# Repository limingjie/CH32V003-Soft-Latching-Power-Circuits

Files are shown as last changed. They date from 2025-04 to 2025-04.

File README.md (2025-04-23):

# CH32V003 Soft Latching Power Circuits

The Soft Latching Power Circuit is ideal for battery-powered applications, as it draws no current once the system is powered down.

## Schematic

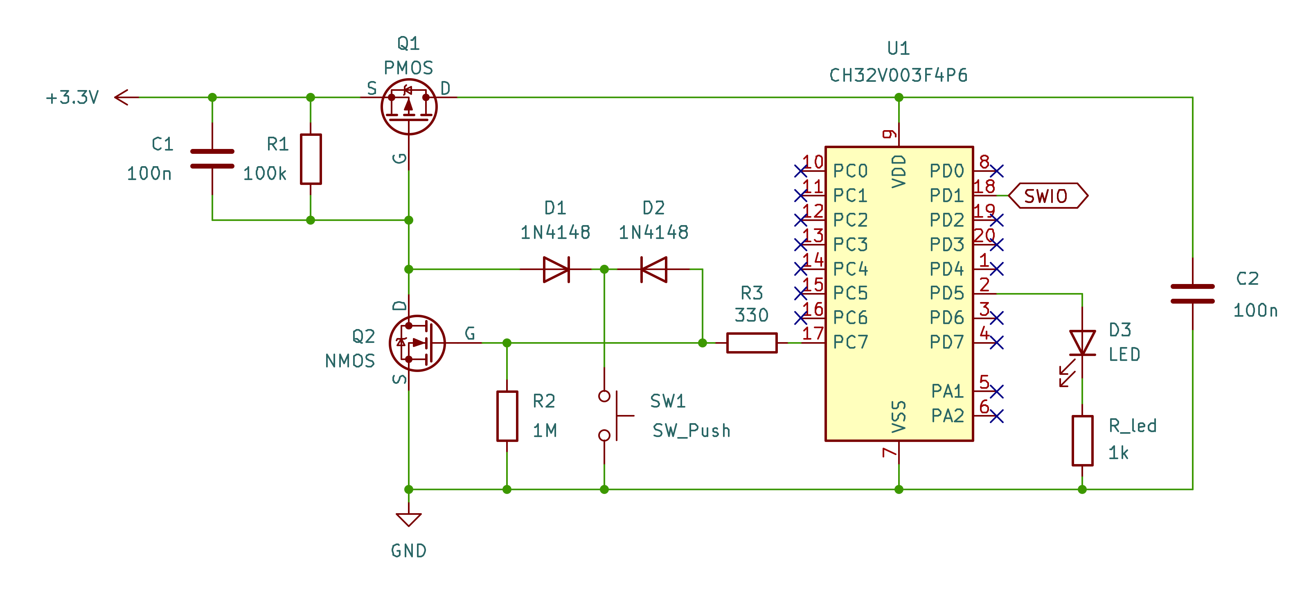
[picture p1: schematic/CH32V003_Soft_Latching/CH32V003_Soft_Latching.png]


- `R1` and `C1` hold `Q1` in the off state, while `R2` keeps `Q2` turned off.
- Pressing the button `SW1` pulls the gate of `Q1` low, allowing power to reach the MCU.
- Once powered, the MCU configures `PC7` as an input with the internal pull-up resistor, which latches both `Q1` and `Q2` on.
- The MCU can also monitor the state of the button through pin `PC7`.
- To shut down the circuit, the MCU configures `PC7` as an input with the internal pull-down resistor, turning off both `Q1` and `Q2`.

## Notes

The circuit works flawlessly with the CH32V003!

Initially, I tested it with the CH552, but it never operated reliably. This is likely due to the CH552’s GPIOs defaulting to quasi-bidirectional mode (typical for 8051 cores), which includes an internal pull-up resistor. As a result, `Q2` may not be fully turned off. In contrast, the CH32V003 GPIOs default to high-impedance input mode, which avoids this issue.

## References

- [Andrew Levido: Soft Latching Power Circuits](https://circuitcellar.com/resources/quickbits/soft-latching-power-circuits/)
- [CNLohr: ch32v003fun](https://github.com/cnlohr/ch32v003fun)
- [A Guide to Debouncing](https://my.eng.utah.edu/~cs5780/debouncing.pdf)
- [The simplest button debounce solution](https://www.e-tinkers.com/2021/05/the-simplest-button-debounce-solution/)
- [Museum of the Game - Let's design some POKEY replacements](https://forums.arcade-museum.com/threads/lets-design-some-pokey-replacements.515774/post-4623716)

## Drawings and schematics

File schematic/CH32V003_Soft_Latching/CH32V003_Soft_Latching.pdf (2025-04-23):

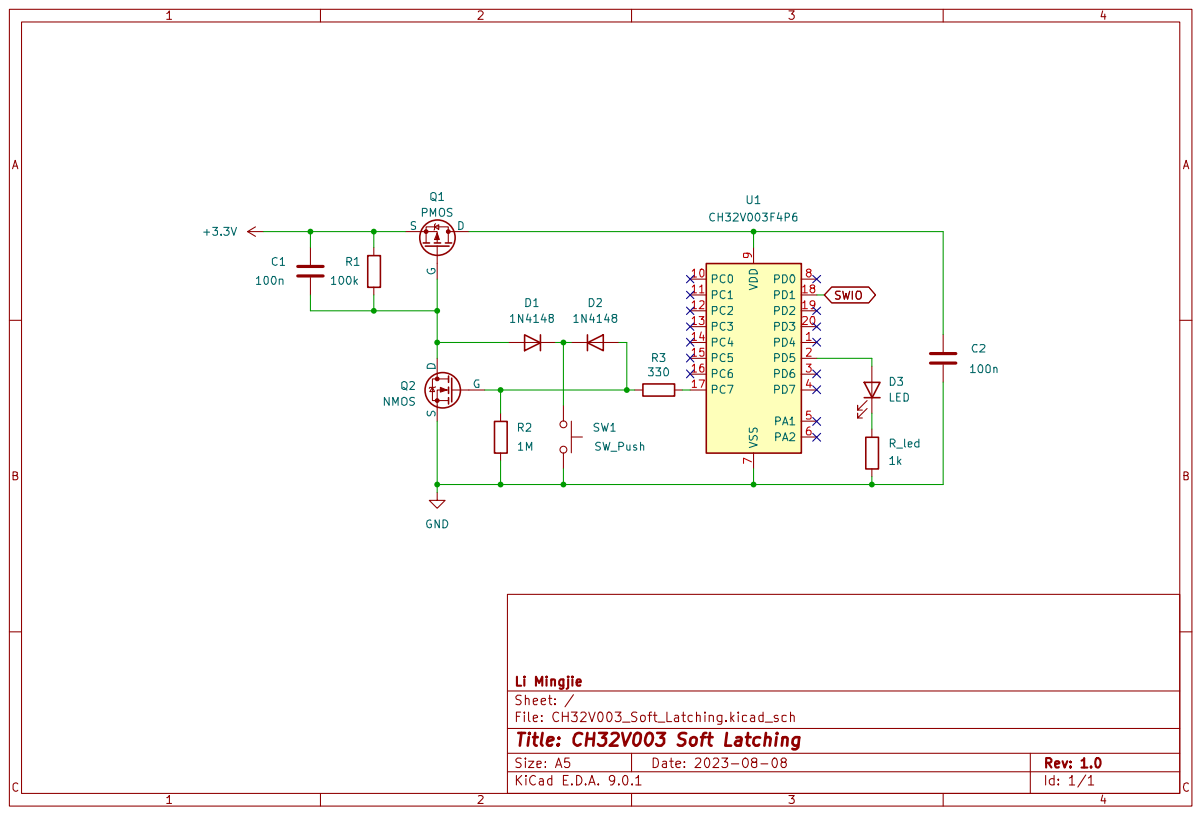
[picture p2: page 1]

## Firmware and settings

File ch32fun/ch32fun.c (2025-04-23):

// Mixture of embedlibc, and ch32v00x_startup.c
// Use with newlib headers.
// Mixture of weblibc, mini-printf and ???
/* This file contains the following functions:

// libc (via musl) mixture and miniprintf

int printf( const char* format, ... )
int vprintf(const char* format, va_list args)
int snprintf( char * buffer, unsigned int buffer_len, const char* format, ... )
int sprintf( char * buffer, const char * format, ... )
size_t wcrtomb(char *restrict s, wchar_t wc, mbstate_t *restrict st)
int wctomb(char *s, wchar_t wc)
size_t strlen(const char *s)
size_t strnlen(const char *s, size_t n)
void *memset(void *dest, int c, size_t n)
char *strcpy(char *d, const char *s)
char *strncpy(char *d, const char *s, size_t n)
int strcmp(const char *l, const char *r)
int strncmp(const char *_l, const char *_r, size_t n)
static char *twobyte_strstr(const unsigned char *h, const unsigned char *n)
static char *threebyte_strstr(const unsigned char *h, const unsigned char *n)
static char *fourbyte_strstr(const unsigned char *h, const unsigned char *n)
static char *twoway_strstr(const unsigned char *h, const unsigned char *n)
char *strstr(const char *h, const char *n)
char *strchr(const char *s, int c)
void *__memrchr(const void *m, int c, size_t n)
char *strrchr(const char *s, int c)
void *memcpy(void *dest, const void *src, size_t n)
int memcmp(const void *vl, const void *vr, size_t n)
void *memmove(void *dest, const void *src, size_t n)
void *memchr(const void *src, int c, size_t n)
int puts(const char *s)
int mini_itoa(long value, unsigned int radix, int uppercase, int unsig,
	 char *buffer)
int mini_vsnprintf(char *buffer, unsigned int buffer_len, const char *fmt, va_list va)
int mini_vpprintf(int (*puts)(char* s, int len, void* buf), void* buf, const char *fmt, va_list va)
int mini_snprintf(char* buffer, unsigned int buffer_len, const char *fmt, ...)
int mini_pprintf(int (*puts)(char*s, int len, void* buf), void* buf, const char *fmt, ...)

// IRQ Handling Code
void DefaultIRQHandler( void )
void NMI_RCC_CSS_IRQHandler( void )

// Startup Code
void InterruptVectorDefault( void )
void handle_reset( void )

// Configuration-specific I/O

#if defined( FUNCONF_USE_UARTPRINTF ) && FUNCONF_USE_UARTPRINTF
void SetupUART( int uartBRR )
int _write(int fd, const char *buf, int size)
int putchar(int c)
#endif

#if defined( FUNCONF_USE_DEBUGPRINTF ) && FUNCONF_USE_DEBUGPRINTF
void handle_debug_input( int numbytes, uint8_t * data ) // You can override this!
void poll_input( void )
int _write(int fd, const char *buf, int size)
int putchar(int c)
void SetupDebugPrintf( void )
void WaitForDebuggerToAttach()
#endif

#if (defined( FUNCONF_USE_DEBUGPRINTF ) && !FUNCONF_USE_DEBUGPRINTF) && \
	(defined( FUNCONF_USE_UARTPRINTF ) && !FUNCONF_USE_UARTPRINTF) && \
	(defined( FUNCONF_NULL_PRINTF ) && FUNCONF_NULL_PRINTF)

int _write(int fd, const char *buf, int size)
int putchar(int c)
#endif

void DelaySysTick( uint32_t n )
void SystemInit( void )

#ifdef CPLUSPLUS
extern void __cxa_pure_virtual()
void __libc_init_array(void)
#endif

*/

// We pre-define these, because if the user is (for some awful reason) using gcc-riscv64-linux-gnu with newlib, it will fail to compile if it janks up the stdio/string functions.
#define _SSP_STRING_H_
#define _SSP_STDIO_H_

#include <stdio.h>
#include <string.h>
#include <stdarg.h>
#include <limits.h>
#include <stdint.h>
#include <ch32fun.h>

#define WEAK __attribute__((weak))

WEAK int errno;

static int __puts_uart( char *s, int len, void *buf )
{
	(void)buf;

	_write( 0, s, len );
	return len;
}

WEAK int printf( const char* format, ... )
{
	va_list args;
	va_start( args, format );
	int ret_status = mini_vpprintf(__puts_uart, 0, format, args);
	va_end( args );
	return ret_status;
}

WEAK int vprintf(const char* format, va_list args)
{
	return mini_vpprintf(__puts_uart, 0, format, args);
}

WEAK int snprintf( char * buffer, unsigned int buffer_len, const char* format, ... )
{
	va_list args;
	va_start( args, format );
	int ret = mini_vsnprintf( buffer, buffer_len, format, args );
	va_end( args );
	return ret;
}

WEAK int sprintf( char * buffer, const char * format, ... )
{
	va_list args;
	va_start( args, format );
	int ret = mini_vsnprintf( buffer, INT_MAX, format, args );
	va_end( args );
	return ret;
}

/* Some stuff from MUSL


----------------------------------------------------------------------
Copyright © 2005-2020 Rich Felker, et al.

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
THE SOFTWARE IS PROVIDED "AS IS", WITHOUT WARRANTY OF ANY KIND,
EXPRESS OR IMPLIED, INCLUDING BUT NOT LIMITED TO THE WARRANTIES OF
MERCHANTABILITY, FITNESS FOR A PARTICULAR PURPOSE AND NONINFRINGEMENT.
IN NO EVENT SHALL THE AUTHORS OR COPYRIGHT HOLDERS BE LIABLE FOR ANY
CLAIM, DAMAGES OR OTHER LIABILITY, WHETHER IN AN ACTION OF CONTRACT,
TORT OR OTHERWISE, ARISING FROM, OUT OF OR IN CONNECTION WITH THE
SOFTWARE OR THE USE OR OTHER DEALINGS IN THE SOFTWARE.
----------------------------------------------------------------------

*/

/*
 * mbstate_t is an opaque object to keep conversion state, during multibyte
 * stream conversions.  The content must not be referenced by user programs.
 */

#define CURRENT_UTF8 0
#define IS_CODEUNIT(c) ((unsigned)(c)-0xdf80 < 0x80)
#define MB_CUR_MAX (CURRENT_UTF8 ? 4 : 1)

typedef void * mbstate_t;

#ifdef UNICODE
WEAK size_t wcrtomb(char *restrict s, wchar_t wc, mbstate_t *restrict st)
{
	if (!s) return 1;
	if ((unsigned)wc < 0x80) {
		*s = wc;
		return 1;
	} else if (MB_CUR_MAX == 1) {
		if (!IS_CODEUNIT(wc)) {
			errno = 0x02; // EILSEQ
			return -1;
		}
		*s = wc;
		return 1;
	} else if ((unsigned)wc < 0x800) {
		*s++ = 0xc0 | (wc>>6);
		*s = 0x80 | (wc&0x3f);
		return 2;
	} else if ((unsigned)wc < 0xd800 || (unsigned)wc-0xe000 < 0x2000) {
		*s++ = 0xe0 | (wc>>12);
		*s++ = 0x80 | ((wc>>6)&0x3f);
		*s = 0x80 | (wc&0x3f);
		return 3;
	} else if ((unsigned)wc-0x10000 < 0x100000) {
		*s++ = 0xf0 | (wc>>18);
		*s++ = 0x80 | ((wc>>12)&0x3f);
		*s++ = 0x80 | ((wc>>6)&0x3f);
		*s = 0x80 | (wc&0x3f);
		return 4;
	}
	errno = 0x02;//EILSEQ;
	return -1;
}
WEAK int wctomb(char *s, wchar_t wc)
{
	if (!s) return 0;
	return wcrtomb(s, wc, 0);
}
#endif
WEAK size_t strlen(const char *s)
{
	const char *a = s;
	for (; *s; s++);
	return s-a;
}
WEAK size_t strnlen(const char *s, size_t n) { const char *p = memchr(s, 0, n); return p ? (size_t)(p-s) : n;}
WEAK void *memset(void *dest, int c, size_t n) { unsigned char *s = dest; for (; n; n--, s++) *s = c; return dest; }
WEAK char *strcpy(char *d, const char *s)
{
	char *d0=d;
	for (; (*d=*s); s++, d++);
	return d0;
}
WEAK char *strncpy(char *d, const char *s, size_t n)
{
	char *d0=d;
	for (; n && (*d=*s); n--, s++, d++);
	return d0;
}
WEAK int strcmp(const char *l, const char *r)
{
	for (; *l==*r && *l; l++, r++);
	return *(unsigned char *)l - *(unsigned char *)r;
}
WEAK int strncmp(const char *_l, const char *_r, size_t n)
{
	const unsigned char *l=(void *)_l, *r=(void *)_r;
	if (!n--) return 0;
	for (; *l && *r && n && *l == *r ; l++, r++, n--);
	return *l - *r;
}

static char *twobyte_strstr(const unsigned char *h, const unsigned char *n)
{
	uint16_t nw = n[0]<<8 | n[1], hw = h[0]<<8 | h[1];
	for (h++; *h && hw != nw; hw = hw<<8 | *++h);
	return *h ? (char *)h-1 : 0;
}

static char *threebyte_strstr(const unsigned char *h, const unsigned char *n)
{
	uint32_t nw = (uint32_t)n[0]<<24 | n[1]<<16 | n[2]<<8;
	uint32_t hw = (uint32_t)h[0]<<24 | h[1]<<16 | h[2]<<8;
	for (h+=2; *h && hw != nw; hw = (hw|*++h)<<8);
	return *h ? (char *)h-2 : 0;
}

static char *fourbyte_strstr(const unsigned char *h, const unsigned char *n)
{
	uint32_t nw = (uint32_t)n[0]<<24 | n[1]<<16 | n[2]<<8 | n[3];
	uint32_t hw = (uint32_t)h[0]<<24 | h[1]<<16 | h[2]<<8 | h[3];
	for (h+=3; *h && hw != nw; hw = hw<<8 | *++h);
	return *h ? (char *)h-3 : 0;
}

#define MAX(a,b) ((a)>(b)?(a):(b))
#define MIN(a,b) ((a)<(b)?(a):(b))

#define BITOP(a,b,op) \
 ((a)[(size_t)(b)/(8*sizeof *(a))] op (size_t)1<<((size_t)(b)%(8*sizeof *(a))))

static char *twoway_strstr(const unsigned char *h, const unsigned char *n)
{
	const unsigned char *z;
	size_t l, ip, jp, k, p, ms, p0, mem, mem0;
	size_t byteset[32 / sizeof(size_t)] = { 0 };
	size_t shift[256];

	/* Computing length of needle and fill shift table */
	for (l=0; n[l] && h[l]; l++)
		BITOP(byteset, n[l], |=), shift[n[l]] = l+1;
	if (n[l]) return 0; /* hit the end of h */

	/* Compute maximal suffix */
	ip = -1; jp = 0; k = p = 1;
	while (jp+k<l) {
		if (n[ip+k] == n[jp+k]) {
			if (k == p) {
				jp += p;
				k = 1;
			} else k++;
		} else if (n[ip+k] > n[jp+k]) {
			jp += k;
			k = 1;
			p = jp - ip;
		} else {
			ip = jp++;
			k = p = 1;
		}
	}
	ms = ip;
	p0 = p;

	/* And with the opposite comparison */
	ip = -1; jp = 0; k = p = 1;
	while (jp+k<l) {
		if (n[ip+k] == n[jp+k]) {
			if (k == p) {
				jp += p;
				k = 1;
			} else k++;
		} else if (n[ip+k] < n[jp+k]) {
			jp += k;
			k = 1;
			p = jp - ip;
		} else {
			ip = jp++;
			k = p = 1;
		}
	}
	if (ip+1 > ms+1) ms = ip;
	else p = p0;

	/* Periodic needle? */
	if (memcmp(n, n+p, ms+1)) {
		mem0 = 0;
		p = MAX(ms, l-ms-1) + 1;
	} else mem0 = l-p;
	mem = 0;

	/* Initialize incremental end-of-haystack pointer */
	z = h;

	/* Search loop */
	for (;;) {
		/* Update incremental end-of-haystack pointer */
		if ((size_t)(z-h) < l) {
			/* Fast estimate for MAX(l,63) */
			size_t grow = l | 63;
			const unsigned char *z2 = memchr(z, 0, grow);
			if (z2) {
				z = z2;
				if ((size_t)(z-h) < l) return 0;
			} else z += grow;
		}

		/* Check last byte first; advance by shift on mismatch */
		if (BITOP(byteset, h[l-1], &)) {
			k = l-shift[h[l-1]];
			if (k) {
				if (k < mem) k = mem;
				h += k;
				mem = 0;
				continue;
			}
		} else {
			h += l;
			mem = 0;
			continue;
		}

		/* Compare right half */
		for (k=MAX(ms+1,mem); n[k] && n[k] == h[k]; k++);
		if (n[k]) {
			h += k-ms;
			mem = 0;
			continue;
		}
		/* Compare left half */
		for (k=ms+1; k>mem && n[k-1] == h[k-1]; k--);
		if (k <= mem) return (char *)h;
		h += p;
		mem = mem0;
	}
}

WEAK char *strchr(const char *s, int c)
{
	c = (unsigned char)c;
	do
	{
		char ts = *s;
		if( ts == c ) return (char*)s;
		if( !ts ) return 0;
		s++;
	} while(1);
}

WEAK char *strstr(const char *h, const char *n)
{
	/* Return immediately on empty needle */
	if (!n[0]) return (char *)h;

	/* Use faster algorithms for short needles */
	h = strchr(h, *n);
	if (!h || !n[1]) return (char *)h;
	if (!h[1]) return 0;
	if (!n[2]) return twobyte_strstr((void *)h, (void *)n);
	if (!h[2]) return 0;
	if (!n[3]) return threebyte_strstr((void *)h, (void *)n);
	if (!h[3]) return 0;
	if (!n[4]) return fourbyte_strstr((void *)h, (void *)n);

	return twoway_strstr((void *)h, (void *)n);
}


WEAK void *__memrchr(const void *m, int c, size_t n)
{
	const unsigned char *s = m;
	c = (unsigned char)c;
	while (n--) if (s[n]==c) return (void *)(s+n);
	return 0;
}

WEAK char *strrchr(const char *s, int c)
{
	return __memrchr(s, c, strlen(s) + 1);
}

WEAK void *memcpy(void *dest, const void *src, size_t n)
{
	unsigned char *d = dest;
	const unsigned char *s = src;
	for (; n; n--) *d++ = *s++;
	return dest;
}

WEAK int memcmp(const void *vl, const void *vr, size_t n)
{
	const unsigned char *l=vl, *r=vr;
	for (; n && *l == *r; n--, l++, r++);
	return n ? *l-*r : 0;
}


WEAK void *memmove(void *dest, const void *src, size_t n)
{
	char *d = dest;
	const char *s = src;

	if (d==s) return d;
	if ((uintptr_t)s-(uintptr_t)d-n <= -2*n) return memcpy(d, s, n);

	if (d<s) {
		for (; n; n--) *d++ = *s++;
	} else {
		while (n) n--, d[n] = s[n];
	}

	return dest;
}
WEAK void *memchr(const void *src, int c, size_t n)
{
	const unsigned char *s = src;
	c = (unsigned char)c;
	for (; n && *s != c; s++, n--);
	return n ? (void *)s : 0;
}

WEAK int puts(const char *s)
{
	int sl = strlen( s );
	_write(0, s, sl );
	_write(0, "\n", 1 );
	return sl + 1;
}

/*
 * The Minimal snprintf() implementation
 *
 * Copyright (c) 2013,2014 Michal Ludvig <michal@logix.cz>
 * 
 * Permission granted on 2024-07-13 for optional relicense under MIT license.
 * https://github.com/mludvig/mini-printf/issues/16
 *
 * ----
 *
 * This is a minimal snprintf() implementation optimised
 * for embedded systems with a very limited program memory.
 * mini_snprintf() doesn't support _all_ the formatting
 * the glibc does but on the other hand is a lot smaller.
 * Here are some numbers from my STM32 project (.bin file size):
 *      no snprintf():      10768 bytes
 *      mini snprintf():    11420 bytes     (+  652 bytes)
 *      glibc snprintf():   34860 bytes     (+24092 bytes)
 * Wasting nearly 24kB of memory just for snprintf() on
 * a chip with 32kB flash is crazy. Use mini_snprintf() instead.
 *
 */

#define mini_strlen strlen
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
int main() __attribute__((used));
void SystemInit( void ) __attribute__((used));

extern uint32_t * _sbss;
extern uint32_t * _ebss;
extern uint32_t * _data_lma;
extern uint32_t * _data_vma;
extern uint32_t * _edata;

#if FUNCONF_DEBUG_HARDFAULT
#if FUNCONF_USE_DEBUGPRINTF
void PrintHex( uint32_t n )
{
	while( (*DMDATA0) & 0x80 );
	// Write out character.
	*DMDATA0 = 0x78302088; //" 0x"
	int shift;
	for( shift = 28; shift >= 0; shift -= 4 )
	{
		while( (*DMDATA0) & 0x80 );
		int s = (n>>shift) & 0xf;
		s += ( s < 10 ) ? '0' : ('a' - 10);
		*DMDATA0 = 0x85 | (s<<8); //" 0x"
	}
}
#elif FUNCONF_USE_UARTPRINTF
void PrintHex( uint32_t n )
{
	putchar( ' ' );
	putchar( '0' );
	putchar( 'x' );
	int shift;
	for( shift = 28; shift >= 0; shift -= 4 )
	{
		int s = (n>>shift) & 0xf;
		s += ( s < 10 ) ? '0' : ('a' - 10);
		putchar( s );
	}
}
#endif
#endif

// If you don't override a specific handler, it will just spin forever.
void DefaultIRQHandler( void )
{
#if FUNCONF_DEBUG_HARDFAULT && ( FUNCONF_USE_DEBUGPRINTF || FUNCONF_USE_UARTPRINTF )
	//This is kind of like a crash handler.
	//printf( "DEAD MSTATUS:%08x MTVAL:%08x MCAUSE:%08x MEPC:%08x\n", (int)__get_MSTATUS(), (int)__get_MTVAL(), (int)__get_MCAUSE(), (int)__get_MEPC() );
	PrintHex( __get_MEPC() ); // "addr2line -e debugprintfdemo.elf 0x000007e6" ---> debugprintfdemo.c:45
	PrintHex( __get_MSTATUS() );
	PrintHex( __get_MTVAL() );
	PrintHex( __get_MCAUSE() );
#if FUNCONF_USE_DEBUGPRINTF
	while( (*DMDATA0) & 0x80 );
	*DMDATA0 = 0x0a85;
	while( (*DMDATA0) & 0x80 );
	*DMDATA0 = 0xaaaaaa83;
#elif FUNCONF_USE_UARTPRINTF
	putchar( '\n' );
#endif
#endif
	//printf( "DEAD MSTATUS:%08x MTVAL:%08x MCAUSE:%08x MEPC:%08x\n", (int)__get_MSTATUS(), (int)__get_MTVAL(), (int)__get_MCAUSE(), (int)__get_MEPC() );
	// Infinite Loop
	asm volatile( "1: j 1b" );
}

// This makes it so that all of the interrupt handlers just alias to
// DefaultIRQHandler unless they are individually overridden.

#if defined(FUNCONF_USE_CLK_SEC) && FUNCONF_USE_CLK_SEC
/**
 * @brief 	Non Maskabke Interrupt handler
 * 			Invoked when the Clock Security system
 * 			detects the failure of the HSE oscilator.
 * 			The sys clock is switched to HSI.
 * 			Clears the CSSF flag in RCC->INTR
 */
void NMI_RCC_CSS_IRQHandler( void )
{
	RCC->INTR |= RCC_CSSC;	// clear the clock security int flag
}

void NMI_Handler( void )				__attribute__((section(".text.vector_handler"))) __attribute((weak,alias("NMI_RCC_CSS_IRQHandler"))) __attribute__((used));
#else
void NMI_Handler( void )				__attribute__((section(".text.vector_handler"))) __attribute((weak,alias("DefaultIRQHandler"))) __attribute__((used));
#endif
void HardFault_Handler( void )			__attribute__((section(".text.vector_handler"))) __attribute((weak,alias("DefaultIRQHandler"))) __attribute__((used));
void Ecall_M_Mode_Handler( void )		__attribute__((section(".text.vector_handler"))) __attribute((weak,alias("DefaultIRQHandler"))) __attribute__((used));
void Ecall_U_Mode_Handler( void )		__attribute__((section(".text.vector_handler"))) __attribute((weak,alias("DefaultIRQHandler"))) __attribute__((used));
void Break_Point_Handler( void )		__attribute__((section(".text.vector_handler"))) __attribute((weak,alias("DefaultIRQHandler"))) __attribute__((used));
void SysTick_Handler( void )			__attribute__((section(".text.vector_handler"))) __attribute((weak,alias("DefaultIRQHandler"))) __attribute__((used));
void SW_Handler( void )					__attribute__((section(".text.vector_handler"))) __attribute((weak,alias("DefaultIRQHandler"))) __attribute__((used));
void WWDG_IRQHandler( void )			__attribute__((section(".text.vector_handler"))) __attribute((weak,alias("DefaultIRQHandler"))) __attribute__((used));
void PVD_IRQHandler( void )				__attribute__((section(".text.vector_handler"))) __attribute((weak,alias("DefaultIRQHandler"))) __attribute__((used));
void TAMPER_IRQHandler( void )			__attribute__((section(".text.vector_handler"))) __attribute((weak,alias("DefaultIRQHandler"))) __attribute__((used));
void RTC_IRQHandler( void )				__attribute__((section(".text.vector_handler"))) __attribute((weak,alias("DefaultIRQHandler"))) __attribute__((used));
void FLASH_IRQHandler( void )			__attribute__((section(".text.vector_handler"))) __attribute((weak,alias("DefaultIRQHandler"))) __attribute__((used));
void RCC_IRQHandler( void )				__attribute__((section(".text.vector_handler"))) __attribute((weak,alias("DefaultIRQHandler"))) __attribute__((used));
void EXTI7_0_IRQHandler( void )			__attribute__((section(".text.vector_handler"))) __attribute((weak,alias("DefaultIRQHandler"))) __attribute__((used));
void AWU_IRQHandler( void )				__attribute__((section(".text.vector_handler"))) __attribute((weak,alias("DefaultIRQHandler"))) __attribute__((used));
void EXTI0_IRQHandler( void )			__attribute__((section(".text.vector_handler"))) __attribute((weak,alias("DefaultIRQHandler"))) __attribute__((used));
void EXTI1_IRQHandler( void )			__attribute__((section(".text.vector_handler"))) __attribute((weak,alias("DefaultIRQHandler"))) __attribute__((used));
void EXTI2_IRQHandler( void )			__attribute__((section(".text.vector_handler"))) __attribute((weak,alias("DefaultIRQHandler"))) __attribute__((used));
void EXTI3_IRQHandler( void )			__attribute__((section(".text.vector_handler"))) __attribute((weak,alias("DefaultIRQHandler"))) __attribute__((used));
void EXTI4_IRQHandler( void )			__attribute__((section(".text.vector_handler"))) __attribute((weak,alias("DefaultIRQHandler"))) __attribute__((used));
void DMA1_Channel1_IRQHandler( void )	__attribute__((section(".text.vector_handler"))) __attribute((weak,alias("DefaultIRQHandler"))) __attribute__((used));
void DMA1_Channel2_IRQHandler( void )	__attribute__((section(".text.vector_handler"))) __attribute((weak,alias("DefaultIRQHandler"))) __attribute__((used));
void DMA1_Channel3_IRQHandler( void )	__attribute__((section(".text.vector_handler"))) __attribute((weak,alias("DefaultIRQHandler"))) __attribute__((used));
void DMA1_Channel4_IRQHandler( void )	__attribute__((section(".text.vector_handler"))) __attribute((weak,alias("DefaultIRQHandler"))) __attribute__((used));
void DMA1_Channel5_IRQHandler( void )	__attribute__((section(".text.vector_handler"))) __attribute((weak,alias("DefaultIRQHandler"))) __attribute__((used));
void DMA1_Channel6_IRQHandler( void )	__attribute__((section(".text.vector_handler"))) __attribute((weak,alias("DefaultIRQHandler"))) __attribute__((used));
void DMA1_Channel7_IRQHandler( void )	__attribute__((section(".text.vector_handler"))) __attribute((weak,alias("DefaultIRQHandler"))) __attribute__((used));
void ADC1_IRQHandler( void ) 			__attribute__((section(".text.vector_handler"))) __attribute((weak,alias("DefaultIRQHandler"))) __attribute__((used));
void ADC1_2_IRQHandler( void )			__attribute__((section(".text.vector_handler"))) __attribute((weak,alias("DefaultIRQHandler"))) __attribute__((used));
void USBFS_IRQHandler( void )			__attribute__((section(".text.vector_handler"))) __attribute((weak,alias("DefaultIRQHandler"))) __attribute__((used));
void USBFSWakeUp_IRQHandler( void )		__attribute__((section(".text.vector_handler"))) __attribute((weak,alias("DefaultIRQHandler"))) __attribute__((used));
void USB_HP_CAN1_TX_IRQHandler( void )	__attribute__((section(".text.vector_handler"))) __attribute((weak,alias("DefaultIRQHandler"))) __attribute__((used));
void USB_LP_CAN1_RX0_IRQHandler( void )	__attribute__((section(".text.vector_handler"))) __attribute((weak,alias("DefaultIRQHandler"))) __attribute__((used));
void CAN1_RX1_IRQHandler( void )		__attribute__((section(".text.vector_handler"))) __attribute((weak,alias("DefaultIRQHandler"))) __attribute__((used));
void CAN1_SCE_IRQHandler( void )		__attribute__((section(".text.vector_handler"))) __attribute((weak,alias("DefaultIRQHandler"))) __attribute__((used));
void EXTI9_5_IRQHandler( void )			__attribute__((section(".text.vector_handler"))) __attribute((weak,alias("DefaultIRQHandler"))) __attribute__((used));
void TIM1_BRK_IRQHandler( void )		__attribute__((section(".text.vector_handler"))) __attribute((weak,alias("DefaultIRQHandler"))) __attribute__((used));
void TIM1_UP_IRQHandler( void )			__attribute__((section(".text.vector_handler"))) __attribute((weak,alias("DefaultIRQHandler"))) __attribute__((used));
void TIM1_TRG_COM_IRQHandler( void )	__attribute__((section(".text.vector_handler"))) __attribute((weak,alias("DefaultIRQHandler"))) __attribute__((used));
void TIM1_CC_IRQHandler( void )			__attribute__((section(".text.vector_handler"))) __attribute((weak,alias("DefaultIRQHandler"))) __attribute__((used));
void TIM2_IRQHandler( void )			__attribute__((section(".text.vector_handler"))) __attribute((weak,alias("DefaultIRQHandler"))) __attribute__((used));
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

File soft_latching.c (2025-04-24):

/*
 * CH32V003 Soft Latching
 *
 * Reference:
 *  - https://circuitcellar.com/resources/quickbits/soft-latching-power-circuits/
 *  - https://github.com/cnlohr/ch32v003fun
 *
 * Apr 2025 by Li Mingjie
 *  - Email:  limingjie@outlook.com
 *  - GitHub: https://github.com/limingjie/
 */

#include <stdio.h>
#include "ch32fun.h"

uint8_t  button_pin  = PC7;      // Latch and button pin
uint8_t  blink_pin   = PD5;      // LED pin
uint8_t  blink_state = FUN_LOW;  // LED on
uint32_t blink_delay = 500;      // LED blink delay

void systick_init(void)
{
    SysTick->CTLR = 0;
    NVIC_EnableIRQ(SysTicK_IRQn);
    SysTick->CMP  = FUNCONF_SYSTEM_CORE_CLOCK / 1000 * blink_delay;
    SysTick->CNT  = 0;
    SysTick->CTLR = SYSTICK_CTLR_STE | SYSTICK_CTLR_STIE | SYSTICK_CTLR_STCLK;
}

void disable_systick(void)
{
    NVIC_DisableIRQ(SysTicK_IRQn);
}

void SysTick_Handler(void) __attribute__((interrupt));
void SysTick_Handler(void)
{
    // SysTick maintains accurate 20ms period
    SysTick->CMP += FUNCONF_SYSTEM_CORE_CLOCK / 1000 * blink_delay;
    SysTick->SR = 0;

    // blink the LED
    funDigitalWrite(blink_pin, blink_state);
    blink_state = (blink_state == FUN_LOW) ? FUN_HIGH : FUN_LOW;
}

int main()
{
    SystemInit();
    Delay_Ms(100);

    funGpioInitAll();
    // Power on latch
    funPinMode(button_pin, GPIO_CFGLR_IN_PUPD);
    funDigitalWrite(button_pin, FUN_HIGH);  // Input pull-up

    // Init LED pin
    funPinMode(blink_pin, GPIO_Speed_10MHz | GPIO_CNF_OUT_PP);

    systick_init();

    // If the key is holding after power on, wait until it is released.
    // TODO: There should be a more elegant way...
    if (funDigitalRead(button_pin) == FUN_LOW)
    {
        while (1)
        {
            if (funDigitalRead(button_pin) == FUN_HIGH)
            {
                Delay_Ms(5);
                if (funDigitalRead(button_pin) == FUN_HIGH)
                {
                    break;
                }
            }
            Delay_Ms(5);
        }
    }

    // Key states
    // TODO: Create a library
    //  +----------------------------+         +----------------------------+
    //  |  STATE_WAIT_FOR_KEY_PRESS  | <-----> |  STATE_KEY_PRESS_DEBOUNCE  |
    //  +----------------------------+         +----------------------------+
    //                ^                                      |
    //                |                                      V
    //  +----------------------------+         +----------------------------+
    //  | STATE_KEY_RELEASE_DEBOUNCE | <-----> | STATE_WAIT_FOR_KEY_RELEASE |
    //  +----------------------------+         +----------------------------+

    enum debounce_states
    {
        STATE_WAIT_FOR_KEY_PRESS,
        STATE_KEY_PRESS_DEBOUNCE,
        STATE_WAIT_FOR_KEY_RELEASE,
        STATE_KEY_RELEASE_DEBOUNCE
    };

    enum key_states
    {
        KEY_UP,
        KEY_DOWN
    };

    enum key_events
    {
        KEY_NONE,
        KEY_PRESS,
        KEY_RELEASE,
        KEY_LONG_PRESS_RELEASE
    };

#define DEBOUNCE_INTERVAL      5    // 5ms
#define DEBOUNCE_STABLE_CYCLES 5    // 5ms x 5 = 25ms
#define LONG_PRESS_CYCLES      100  // 5ms x 100 = 500ms

    uint8_t  debounce_state           = STATE_WAIT_FOR_KEY_PRESS;
    uint8_t  key_event                = KEY_NONE;
    uint8_t  key_long_press           = 0;
    uint16_t key_cycle_count          = 0;
    uint16_t key_debounce_cycle_count = 0;

    while (1)
    {
        uint8_t key_state = (funDigitalRead(button_pin) == FUN_LOW) ? KEY_DOWN : KEY_UP;
        switch (debounce_state)
        {
            case STATE_WAIT_FOR_KEY_PRESS:
                if (key_state == KEY_DOWN)  // pressed
                {
                    key_debounce_cycle_count = 0;
                    debounce_state           = STATE_KEY_PRESS_DEBOUNCE;
                    printf("STATE_KEY_PRESS_DEBOUNCE\n");
                }
                break;
            case STATE_KEY_PRESS_DEBOUNCE:
                ++key_debounce_cycle_count;
                if (key_state == KEY_DOWN)  // still pressed
                {
                    if (key_debounce_cycle_count >= DEBOUNCE_STABLE_CYCLES)
                    {
                        key_event       = KEY_PRESS;
                        key_cycle_count = 0;
                        key_long_press  = 0;
                        debounce_state  = STATE_WAIT_FOR_KEY_RELEASE;
                        printf("STATE_WAIT_FOR_KEY_RELEASE\n");
                    }
                }
                else
                {
                    debounce_state = STATE_WAIT_FOR_KEY_PRESS;
                    printf("STATE_WAIT_FOR_KEY_PRESS\n");
                }
                break;
            case STATE_WAIT_FOR_KEY_RELEASE:
                ++key_cycle_count;
                if (key_state == KEY_UP)  // released
                {
                    if (key_cycle_count >= LONG_PRESS_CYCLES)
                    {
                        key_long_press = 1;
                        printf("Long Press!!! cycle = %d\n", key_cycle_count);
                    }
                    key_debounce_cycle_count = 0;
                    debounce_state           = STATE_KEY_RELEASE_DEBOUNCE;
                    printf("STATE_KEY_RELEASE_DEBOUNCE\n");
                }
                break;
            case STATE_KEY_RELEASE_DEBOUNCE:
                ++key_debounce_cycle_count;
                if (key_state == KEY_UP)  // still released
                {
                    if (key_debounce_cycle_count >= DEBOUNCE_STABLE_CYCLES)
                    {
                        key_event      = key_long_press ? KEY_LONG_PRESS_RELEASE : KEY_RELEASE;
                        debounce_state = STATE_WAIT_FOR_KEY_PRESS;
                        printf("STATE_WAIT_FOR_KEY_PRESS\n");
                    }
                }
                else
                {
                    debounce_state = STATE_WAIT_FOR_KEY_RELEASE;
                    printf("STATE_WAIT_FOR_KEY_RELEASE\n");
                }
                break;
        }

        // if (key_state)
        // {
        //     disable_systick();
        //     funDigitalWrite(blink_pin, FUN_LOW);
        // }

        if (key_event == KEY_LONG_PRESS_RELEASE)
        {
            key_event = KEY_NONE;
            funDigitalWrite(button_pin, FUN_LOW);  // Input pull-down
            // disable_systick();
            // funDigitalWrite(blink_pin, FUN_HIGH);
        }
        else if (key_event == KEY_RELEASE)
        {
            key_event   = KEY_NONE;
            blink_delay = (blink_delay == 500) ? 100 : 500;
            printf("Key Released. blink_delay = %ld\n", blink_delay);
            systick_init();  // Re-initiate systick, change LED blink interval.
        }

        Delay_Ms(DEBOUNCE_INTERVAL);
    }
}

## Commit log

2023-08-08 Add schematic
    [CH32V003_Soft_Latching.kicad_pcb, CH32V003_Soft_Latching.kicad_sch]
2025-04-23 Update schematic to latch and input
    [CH32V003_Soft_Latching.kicad_sch]
2025-04-23 Update schematic
    [CH32V003_Soft_Latching.kicad_sch]
2025-04-23 Use KiCad symbol for CH32V003
2025-04-23 Remove PCB file
    [CH32V003_Soft_Latching.kicad_pcb]
2025-04-24 Long press to power off

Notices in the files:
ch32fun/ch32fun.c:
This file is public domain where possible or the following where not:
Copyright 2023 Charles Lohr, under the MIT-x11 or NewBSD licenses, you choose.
